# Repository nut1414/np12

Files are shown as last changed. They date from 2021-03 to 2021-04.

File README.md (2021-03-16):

# np12
 yet another 12 keys macro pad using [QMK Firmware](https://github.com/qmk/qmk_firmware)

np12

## Parts
 - a generic Arduino Pro Micro (or other pin compatible)
 - 12x MX Switches
 - an EC11 encoder
 - *(Optional)* a 6mm button for entering the bootloader
 - *(Optional)* 12x Kailh hot-swap sockets
 - *(Optional)* PJ320a TRRS Jack if you want to do a split-board

## Pin Configuration
 |Row|Pin|Arduino Wire Pin|
 |:--:|:--:|:--:|
 |0|D7|6|
 |1|E6|7|
 |2|B4|8|
 |3*|F6|A1|

 |Col|Pin|Arduino Wire Pin|
 |:--:|:--:|:--:|
 |0|D1|2|
 |1|D0|3|
 |2|D4|4|
 |3|C6|5|
 |4*|F7|A0|
 
 *Used only for rotary encoder switch.
 
 |Pin|Arduino Wire Pin||
 |:--:|:--:|:--:|
 |PF5,PF4|A2,A3|Used for encoder|
 |PD2|RX1|Used for handling serial on TRRS audio jack|

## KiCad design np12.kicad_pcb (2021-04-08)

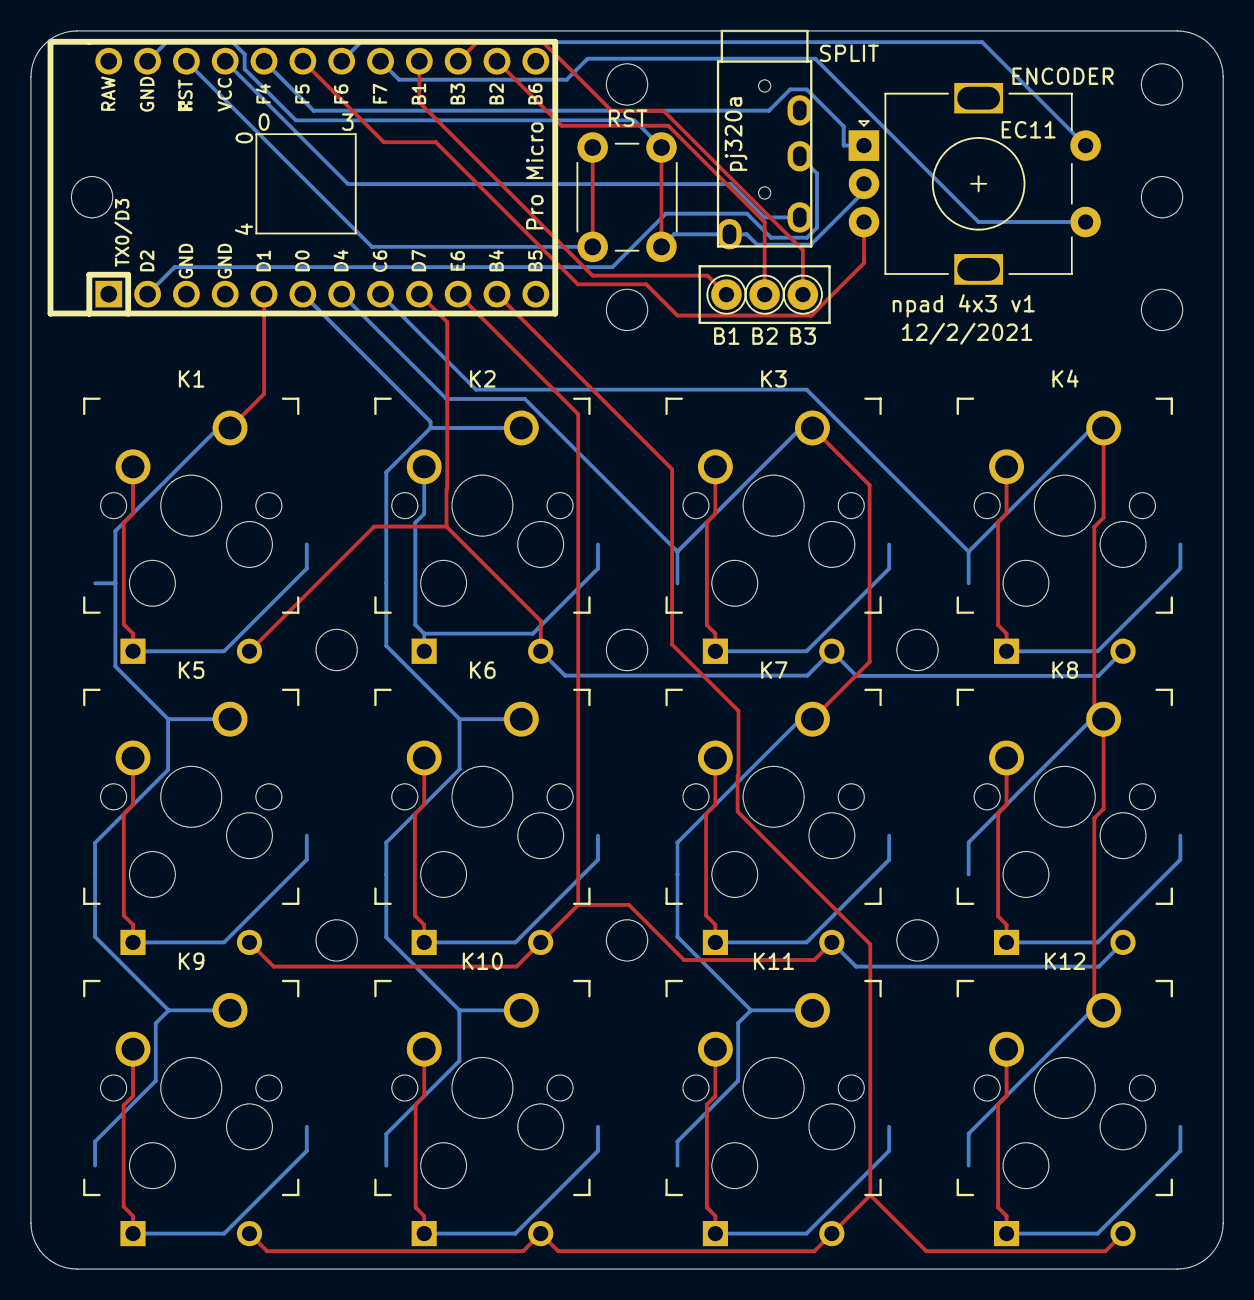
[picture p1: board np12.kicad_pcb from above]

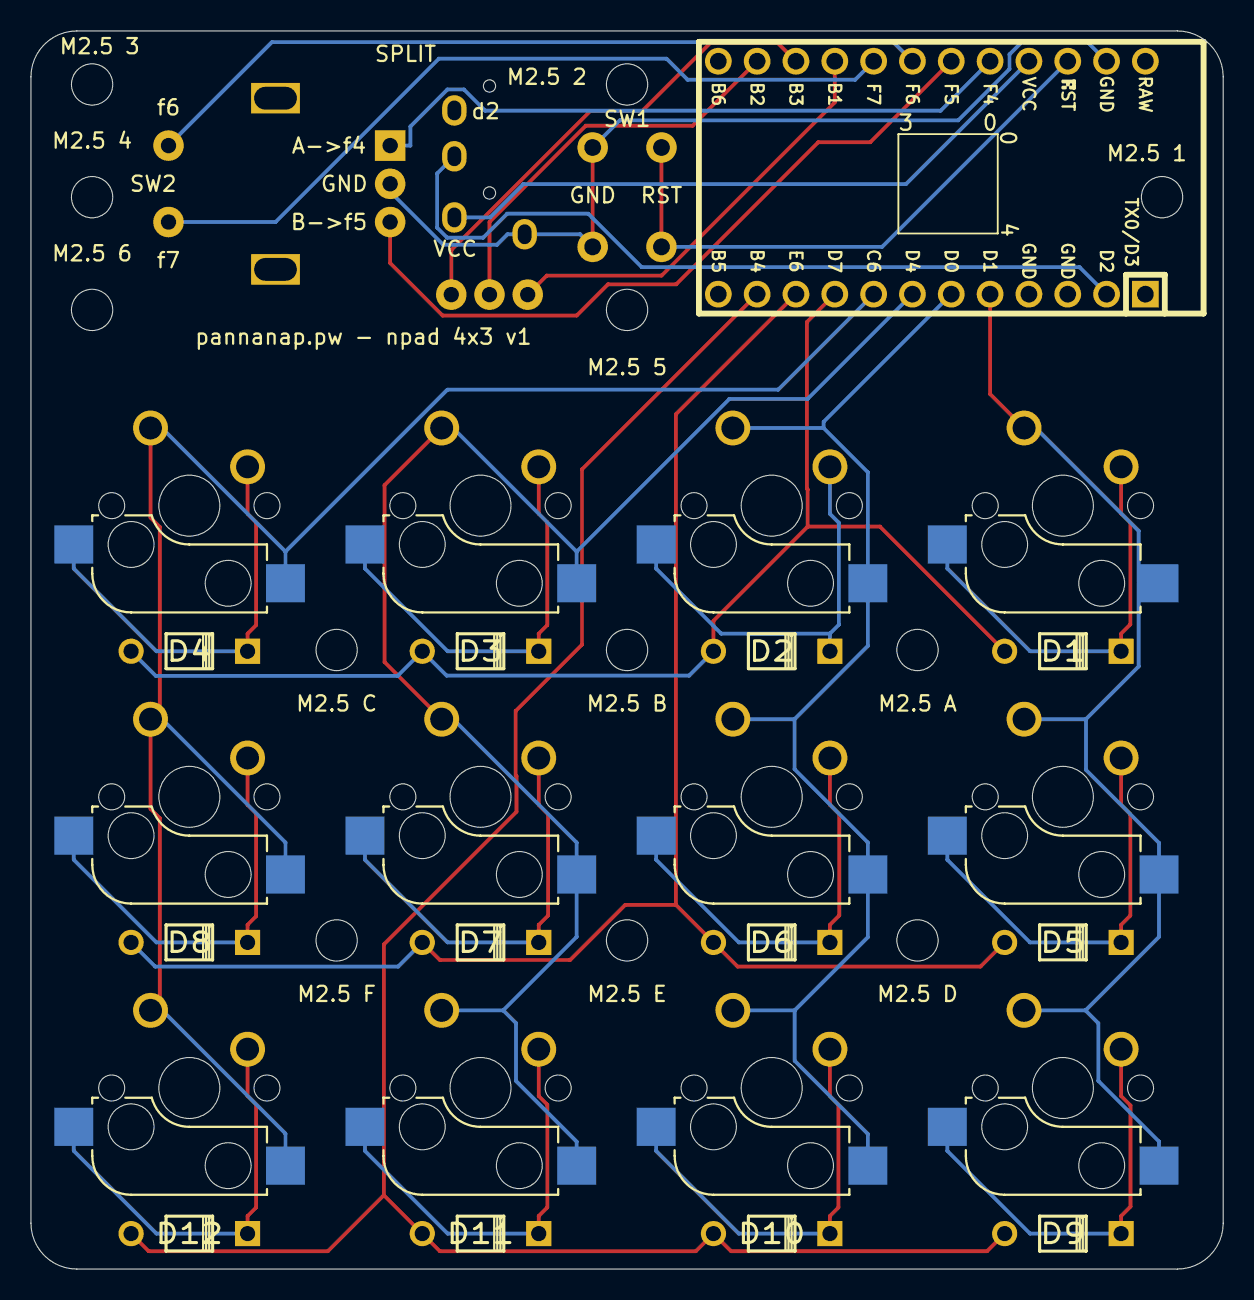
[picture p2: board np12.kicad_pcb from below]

Board: 2 copper layers, 78.0 x 81.0 mm, 43 parts (12 on the bottom side), 30 nets.

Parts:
B1, B2, B3: Pin_D1.0mm_L10.0mm
D1, D2, D3, D4, D5, D6, D7, D8, D9, D10, D11, D12: D; Diode
K1, K2, K3, K4, K5, K6, K7, K8, K9, K10, K11, K12: KEYSW; Kailh_socket_MX_optional
M2.5 1, M2.5 2, M2.5 3, M2.5 4, M2.5 5, M2.5 6, M2.5 A, M2.5 B, M2.5 C, M2.5 D, M2.5 E, M2.5 F: MountingHole_2.7mm_M2.5
SW1: SW_Push; SW_PUSH_6mm
SW2: Rotary_Encoder_Switch; RotaryEncoder_Alps_EC11E-Switch_Vertical_H20mm
U1: ProMicro; ArduinoProMicro
U2: TRRS; TRRS-PJ-320A

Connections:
/b1: B1.1, U1.16
/b2: B2.1, U1.14
/b3: B3.1, U1.15
/col0: K1.1, K5.1, K9.1, U1.5
/col1: K2.1, K6.1, K10.1, U1.6
/col2: K3.1, K7.1, K11.1, U1.7
/col3: K4.1, K8.1, K12.1, U1.8
/data: U1.2, U2.3
/row0: D1.1, D2.1, D3.1, D4.1, U1.9
/row1: D5.1, D6.1, D7.1, D8.1, U1.10
/row2: D9.1, D10.1, D11.1, D12.1, U1.11
unnamed: D1.2, K1.2
unnamed: D2.2, K2.2
unnamed: D3.2, K3.2
unnamed: D4.2, K4.2
unnamed: D5.2, K5.2
unnamed: D6.2, K6.2
unnamed: D7.2, K7.2
unnamed: D8.2, K8.2
unnamed: D9.2, K9.2
unnamed: D10.2, K10.2
unnamed: D11.2, K11.2
unnamed: D12.2, K12.2
unnamed: SW1.1, SW2.C, U1.23, U2.1
unnamed: SW1.2, U1.22
unnamed: SW2.A, U1.20
unnamed: SW2.B, U1.19
unnamed: SW2.S1, U1.17
unnamed: SW2.S2, U1.18
VCC: U1.21, U2.2

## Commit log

2021-03-16 Update Schematic
    [np12.sch]
2021-04-08 change split data trrs ring to ring 1
    [np12.kicad_pcb, np12.sch]
